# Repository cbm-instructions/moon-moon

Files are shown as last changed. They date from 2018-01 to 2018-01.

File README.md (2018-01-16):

# How to make Halexa

<p align="center">

</p>

## Einleitung
Halexa hilft dem Nutzer dabei einen gesünderen Schlafrythmus zu bekommen, indem sie den Nutzer motiviert abends das Handy rechtzeitig wegzulegen.
Zusätzlich wird die Stimmung des Nutzers nach dem Schlaf abgefragt, um zusammen mit den gesammelten Schlafdaten, einen Rückschluss auf das Schlafverhalten des Nutzers zu schließen.
Das Ergebnis ist eine Statistik, die Laune, Schlafdauer und rechtzeitiges Schlafen in Relation setzt, um dem Nutzer zu zeigen, dass seine Tageslaune von der Schlafqualität abhängt.

## Challenge

> In einer Gesellschaft mit steigender Lebenserwartung, mangelnder Bewegung, sowie
steigendem Übergewicht sind Lösungen gefragt die langfristig helfen die
Gesundheitskosten zu reduzieren, indem sie Menschen zu einem gesünderen Leben
anhalten. Auch Technologie kann hier einen wertvollen Beitrag leisten, indem sie
Menschen dabei unterstützt sich mehr zu bewegen, mehr mit anderen Menschen
gemeinsam zu unternehmen, gesünder zu essen, ein anderes Schlafverhalten zu
entwickeln etc.
Inspiriert von dieser Entwicklung ist es das Ziel Ihrer Challenge, Ideen für „Health and
Well-being“ zu entwickelten und zu lauffähigen Demonstratoren umzusetzen. Diese
sollen zu einer Verbesserung von Wohlbefinden und Gesundheit beitragen. Es ist
dabei Ihre Aufgabe, „smarte“ Objekte zu erschaffen die das Wohlbefinden ihrer
Nutzer nachhaltig verbessern. Diese könne für Kinder, Berufstätige, Studierende,
Senioren oder andere Nutzergruppen sein. Zu diesen Objekten zählen
Außenanlagen, Möbel, Gebäude, Deko-Objekte, usw. Jedes dieser Objekte kann
durch Technologie erweitert werden und so Information sammeln, verbreiten oder
anzeigen. Dabei dürfen die Objekte auch spielerische Elemente besitzen. Eine
Anbindung dieser Objekte an Apps oder Fitnesstracker ist denkbar, steht aber nicht
im Mittelpunkt. Der Fokus Ihres Beitrags soll auf den „smarten Objekten“ liegen.

Daraus ergibt sich folgende Challenge:

> Wie könnten Menschen durch die Interaktion mit intelligenten
> Objekten mehr Wohlbefinden und/oder Gesundheit erlangen?

Zu dieser Challenge haben wir mehrere Interviews geführt, aus denen hervorging, dass viele Studenten zu wenig Schlafen. Einer der Gründe hierfür war, dass die Studenten viel Zeit an Smartphones vor dem Einschlafen verbringen. Das Gerät hält den Studenten durch Licht und Inhalt vom Schlafen ab. Das führt zu einem ungesunden Schlafrythmus und zur Müdigkeit am nächsten Tag. Diese kann zu weiteren Effekten führen, wie z.b. Motivationslosigkeit und einem späteren Einschlafen.

Aufgrund dieser Erkentnisse haben wir den folgenden POV formuliert.

### POV

  > Wie können wir verhindern, dass Studenten vor dem Einschlafen zu lange ihre Zeit,
  in der sie schlafen könnten, mit elektronischen Geräten verschwenden umso ihren
  Schlafrhythmus zu verbessern.

## Bauanleitung

Die Anleitung so wie liste aller benötigten Materialien befindet sich [hier](INSTRUCTIONS.md).

## Code

Der Code für das Projekt wurde in C++ geschrieben und befindet sich [hier](code/).

### Zustandsautomat und die Bedienung

<p align="center">

</p>

Halexa benutzt einen Zustandsautomaten als Basis. Jeder Zustand hat eine eigene Anzeige und mögliche Aktionen.
Halexa beginnt im Standby-Zustand. Dieser Zustand zeigt lediglich die Bereitschaft von Halexa.

Ein tippen auf die Fläche führt zum History-Zustand. Er zeigt den Verlauf der vergangenen Tage an. Ein blauer Punkt zeigt den aktuellen, unbewerteten Tag. Im Uhrzeigersinn vom blauen Punkt aus findet man die vergangenen Tage. Dabei ist der Punkt direkt neben dem blauen Punkt der gestrige Schlaf, der nächste der vorgestrige usw. Nach einer gewissen Zeit schaltet Halexa wieder in den Standby-Zustand.

Sobald die Schlafenszeit erreicht ist (aktuell im Quellcode festgelegt auf 10 Sekunden nach jeder vollen Minute), wechselt Halexa aus dem Standby- und History-Zustand in den SleepingTime-Zustand. Dieser macht den Nutzer darauf aufmerksam, dass er sein Handy weglegen sollte und schlafen gehen sollte. Legt der Nutzer sein Handy ab, wird über den TimeIn-Zustand, ein reiner Animations- und Verzögerungszustand, in den Sleep-State gewechselt.
Verpasst der Nutzer die Schlafenszeit, geht das Gerät in den Standby und wiederholt den Alarm nach einiger Zeit. Es ist zu beachten, dass Halexa das Verpassen speichert. Dieses fließt in die Bewertung als "zu spät schlafen gegangen" ein.

Wird nach dem Schlaf das Handy wieder hochgenommen, erkennt Halexa nach einer kurzen, abbrechbaren, TimeOut-Periode, das Ende des Schlafs und geht in den Bewertungs-Zustand.

Im Bewertungszustand, der ebenfalls einen Standby erlaubt, Hat der Nutzer die Möglichkeit durch Antippen des aufleuchtenden Sektors, seine Stimmung nach dem Schlaf zu bewerten. Fühlt er sich gut und ausgeschlafen, wählt er grün. Falls er müde und schlecht gelaunt ist, wählt er rot. Die Bewertung ist bis zum nächsten Schlafenszeitpunkt möglich. Wird dieser erreicht, geht Halexa wieder in den SleepingTime-Zustand und bewertet den Schlaf negativ. Das soll den Nutzer motivieren rechtzeitig, aber zu einem flexiblen Zeitpunkt, zu bewerten.

## Bewertung des Schlafs

Der Schlaf wird anhand folgender drei Kriterien bewertet:

* rechtzeitiges Schlafen gehen
* ausreichende Schlaflänge
* Laune nach dem Schlaf

Jedes der Kriterien kann der Schlafbewertung einen oder keinen Punkt hinzufügen. Somit sind die Punktzahlen null bis drei möglich.

Ein Schlaf mit drei Punkten wird als sehr positiv bewertet und erhält eine deutlich grüne Farbe in der Statistik.
Ein Schlaf mit weniger als drei Punkten wird als eher negativ betrachtet und resultiert in den rot wirkenden Farben: hellorange (zwei Punkte), dunkelorange (ein Punkt), rot (null Punkte).

Es entsteht also eine Darstellung, die tendenziell die zwei Gruppen "positiv" und "negativ" darstellt,aber in den Punktebereichen null bis zwei trotzdem eine Differenzierung erlaubt.

Ziel der halexa ist es dem Nutzer zu zeigen, dass das Einhalten der drei Schlafkriterien, zu einer besseren Stimmung führen kann. Im idealen Fall zeigt die Statistik eine allmählich grüner werdende Historie.

## Ideen zur Weiterentwicklung

1. Einsätzen eines Vibrationsmotors unter der obersten Platte für Vibrationsfeedback bei der Benutzung der Platte als Eingabegerät.

2. Erweiterung um Einstellungsmenü um Schlafenszeit, Weckzeit und länge des Schlafes einzustellen.

3. Hinzufügen von Kapazitiven Buttons um die oben erwähnten Einstellungen vorzunehmen (Drucksensoren zu ungenau).

4. Erweiterung der Nutzergruppe. Es können beispielsweise andere Ablenkungen, wie Zeitschriften und Bücher, weggelegt werden.

5. Technische Anbindung an Home-Automation z.B. IFTTT oder NFC-Trigger

6. Erweiterung um einen echten persistenten Speicher. Aktuell ist die Statistik nur vorhanden, wenn das Gerät an ist. Sie liegt im flüchtigen Speicher.

7. Erweiterung um ein präzises Zeitmodul.

#### Optische Verbesserungen

1. Absenken der obersten Platte, damit sie mit dem LED-Ring auf einer Höhe ist.

2. Die allgemeine Größe verringern.

3. Höherwertiges Material.

## Das Team

Adrian Endrich und Christopher Hansen

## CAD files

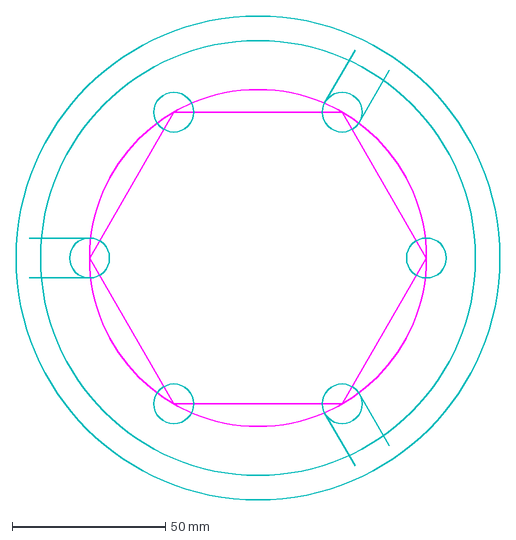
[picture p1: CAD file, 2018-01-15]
lasercutter/komplett.dxf
158.0 x 158.0 mm

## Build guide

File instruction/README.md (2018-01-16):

# Bauanleitung

In diesem Abschnitt befindet sich die komplette Anleitung zum Bau von Halexa. Der Code für den Arduino befindet sich [hier](https://github.com/cbm-instructions/moon-moon/tree/master/code/).

## Materialien und Werkzeuge

### Materialien
* Arduino Uno
* 3x Force Resistance Sensor
* 1 Neopixel LED Ring (4/4)
* Sperrholzplatte 4x460x61 mm
* Kabel
* 1 x Streifenrasterplatine
* 5 Pin Stiftleiste
* 3x 6 Pin Stiftleiste
* 2x 8 Pin Stiftleiste
* 5 x 10 kΩ Widerstände
* Holzleim
* Klebeband
* Rundstab 12 x 12 mm 0,5m (Buche)
* Schmirgelpapier
* Doppelseitiges Klebeband
* Plexiglassscheibe 170x170 mm
* Lötzinn
* Gummiband oder Schnur

### Werkzeuge
* Laser Cutter
* Dremel
* Lötkolben
* Zange
* Heißklebepistole
* Teppichmesser

## Vorbereitung

### Benötigte Vorkenntnisse

* Grundlegende handwerkliche Kentnisse
* Arduino Kentnisse
* Löten
* C++ (alles)

### Zusammenlöten des LED-Rings

### Drucken der Platten

Als erstes werden die SVG-Dateien für den Laser Cutter benötigt. Diese können [hier](https://github.com/cbm-instructions/moon-moon/tree/master/lasercutter/) heruntergeladen werden.

Es müssen folgende SVG-Dateien geschnitten werden hierzu wird die Sperrholzplatte (4x460x61 mm) benutzt:

* Grundplatte.svg
* Stelzenhalter.svg
* LedRingHalterung.svg
* Kabelplatte.svg
* DruckplatteUnten.svg
* DruckplatteOben.svg

* Den größeren der beiden Mäntel in Matel.svg

**Tipp:** Beim schneiden des Mantels ist es wichtig die Stärke des Lasers zu erhöhen, da dieser sonst nicht komplett durchschneidet und der Mantel sonst leicht bricht.

Die geschnittenen Platten sollten ungefähr so aussehen:

<p align="center">
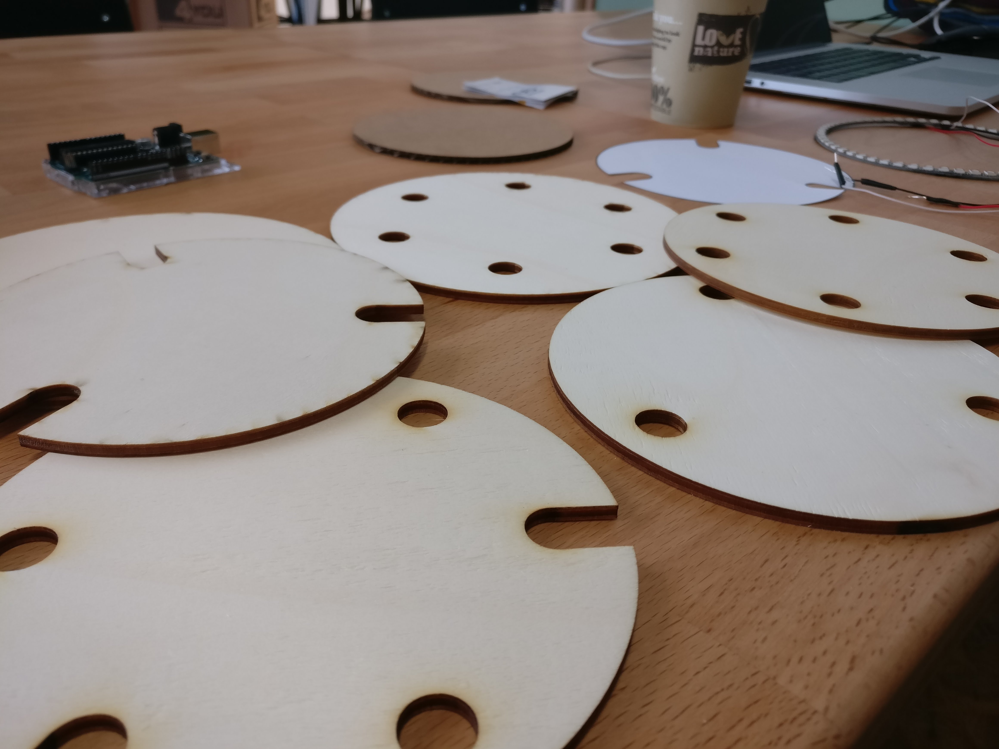
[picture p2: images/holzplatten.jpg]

</p>

Als letztes wird noch einmal die LedRingHalterung benötigt aber diesmal mit der Plexiglassscheibe (170x170 mm). Diese liegt später auf dem LED-Ring.

<p align="center">
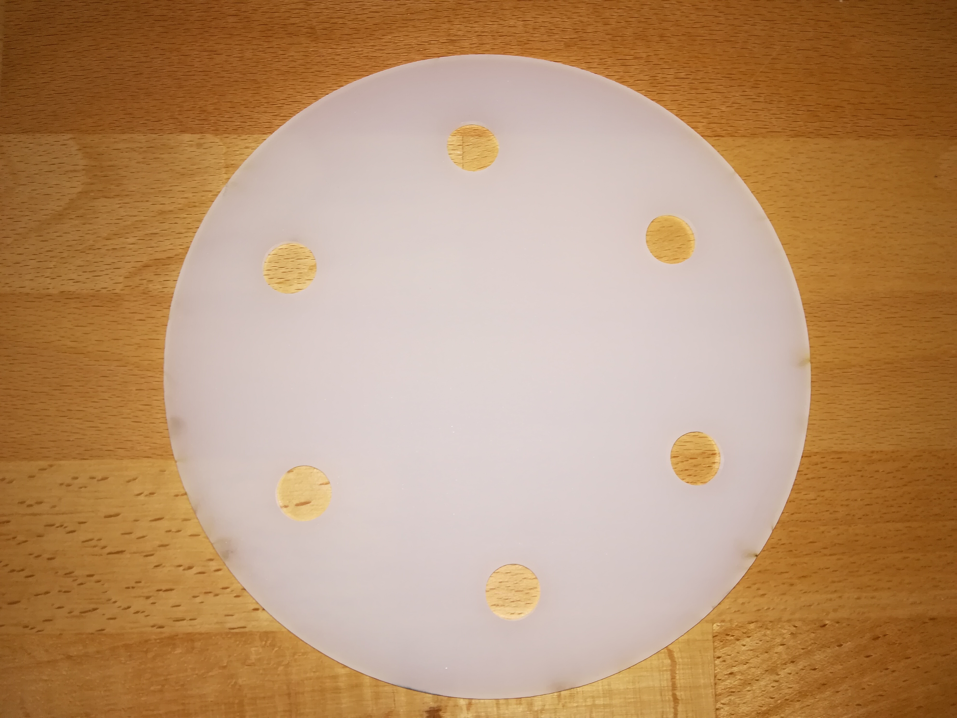
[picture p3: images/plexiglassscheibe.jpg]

</p>

## Schritt für Schritt Anleitung

#### 1. Verkablen der drei Drucksensoren
In diesem Schritt werden die Drucksensoren verkabelt und über eine Platine verbunden, so dass sie später einfacher mit dem Arduino verbunden werden können.

**Benötigte Materialien für diesen Schritt:**
  * Kabel
  * Die drei Drucksensoren
  * Streifenrasterplatine
  * 5 Pin Stiftleiste
  * 2x 6 Pin Stiftleiste
  * 5 x 10 kΩ Widerstände
  * Lötkolben

Als erstes sollten Sie die drei Drucksensoren mit Kabeln verlöten.

<p align="center">
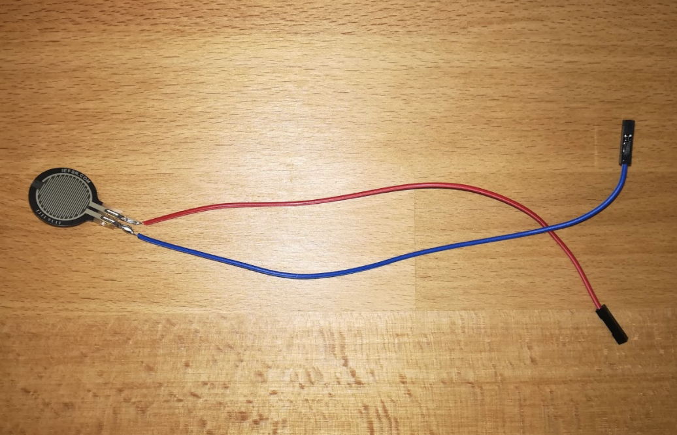
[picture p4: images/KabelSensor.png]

</p>

Danach bauen Sie eine Steckplatine um alle drei Drucksensoren später mit dem Arduino zu verbinden. Die obere waagerechte Steckleiste ist für die Grounds. An den linkesten Stecker dieser Steckleiste wird der Ground des Arduinos befestigt.
An alle anderen Pins werden die Grounds von den drei Drucksensoren befestigt (die zwei zusätzlichen Stecker dienen nur als Ersatz). Der Ground ist mit jeweils einem Widerstand mit jeder der anderen Grounds verbunden. Die Input Pins des Arduinos werden mit den Pins auf der exakt gegenüberliegenden Seite der Grounds verbunden. Die linke horizontale Steckerleiste wird benutzt um alle Sensoren mit dem 5V Eingang des Arduinos zu verbinden.

<p align="center">
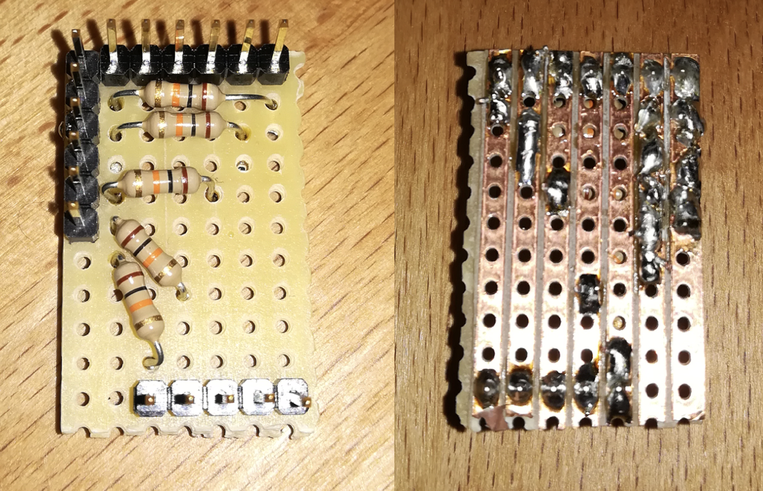
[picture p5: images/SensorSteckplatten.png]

</p>

#### 2. Fertigung der Bodenplatte mit Sensoren

In diesem Schritt werden die Sensoren an die Bodenplatte geklebt und die Stelzenhalterplatte befestigt.

**Benötigte Materialien für diesen Schritt:**
  * Stelzenhalterplatte
  * Bodenplatte
  * Die drei Drucksensoren
  * Holzleim
  * Rundstab 12 x 12 mm 0,5m (Buche)
  * Klebeband
  * Heißklebepistole

Schnittreste vom Laser Cutter:
<p align="center">
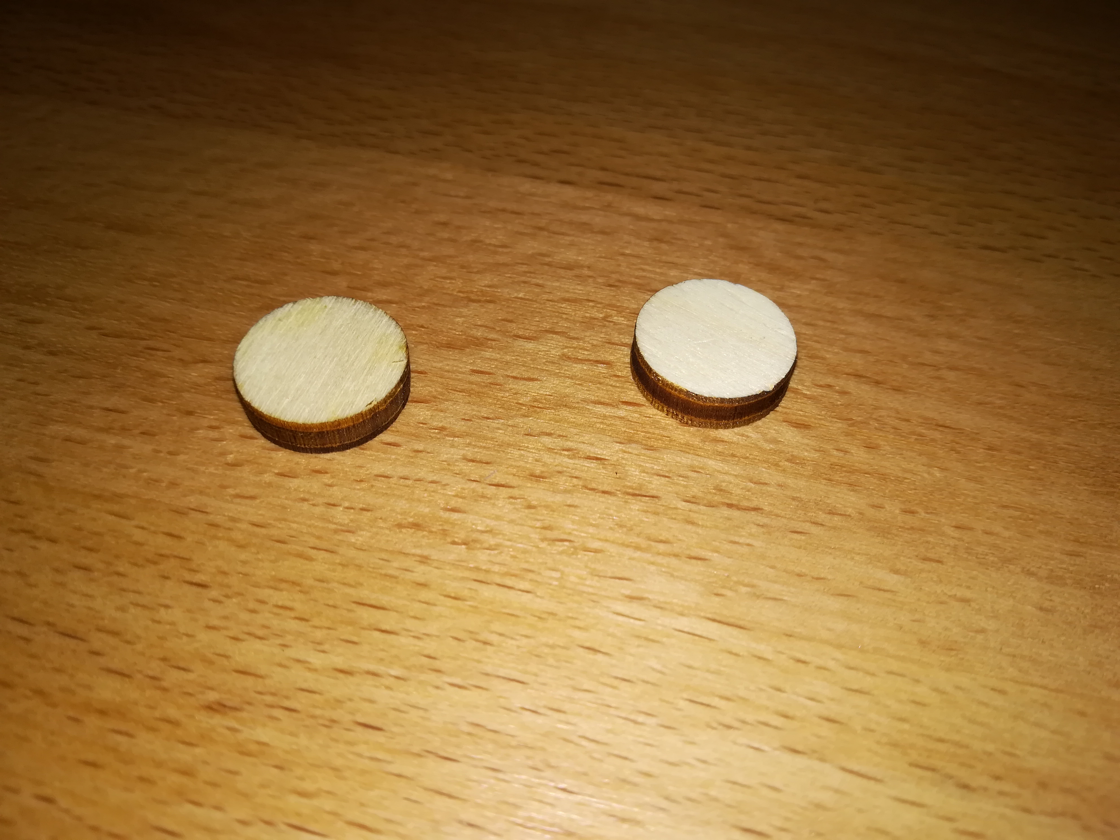
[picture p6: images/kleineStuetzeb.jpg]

</p>

Als erstes sollten Sie die Stelzenhalterplatte mittig auf die Bodenplatte legen und die Stellen markieren an denen die Löcher sind. Auf diese Stellen werden nun die Drucksensoren geklebt (diese haben bereits eine Klebefläche). Danach kann die Stelzenhalterplatte wie vorher auf die Bodenplatte gelegt werden. Wir haben die runden Schnittreste des Laser Cutters als Zwischenstücke benutzt um die Bodenplatte mit der Stelzenhalterplatte zu befästigen, so dass diese nicht die Sensoren berührt. Schneiden Sie drei gleichlange Stücke vom Rundstab (je 70 mm) ab . Kleben Sie diese wie auf dem unteren Bild leicht versetzt zu den Drucksensoren auf die Stelzenhalterplatte (Mit Holzleim oder Heißklebepistole).
Am Schluss können Sie noch die Kabel mit Klebeband fixieren und die Kabel mit der bereits erstellten Steckplatine verbinden.

<p align="center">
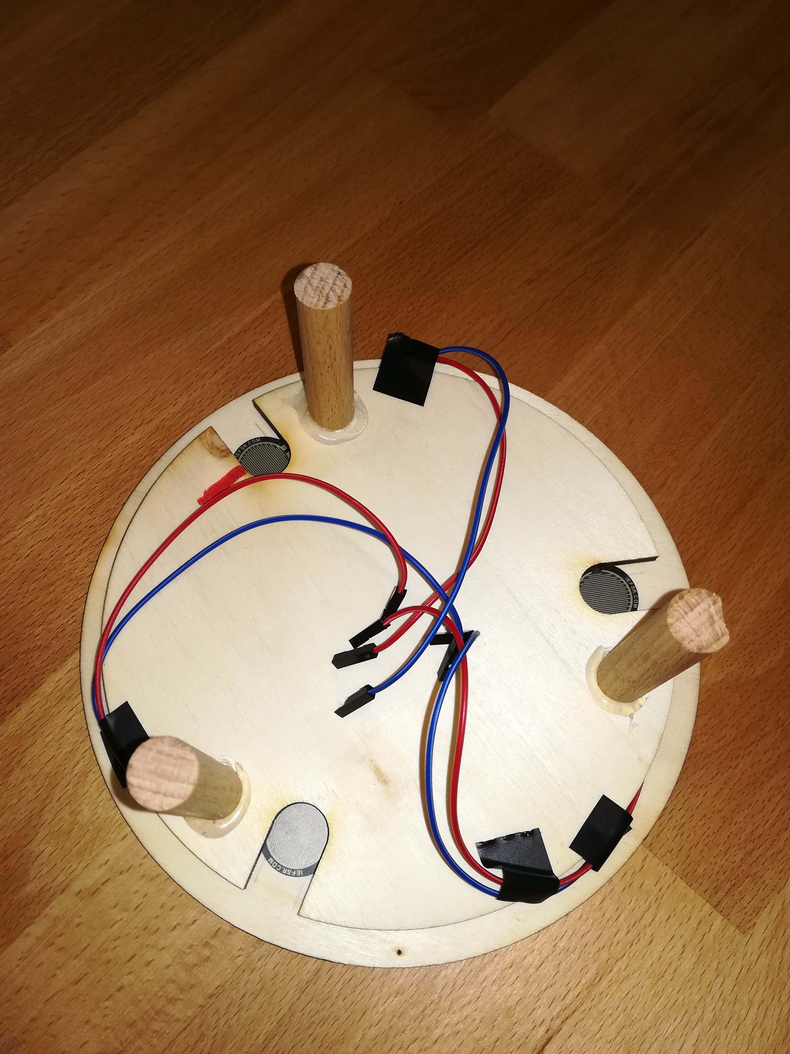
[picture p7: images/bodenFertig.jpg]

</p>

#### 3. Fertigung der LED-Ring Platte

In diesem Schritt wird die Platte die den LED-Ring hält erstellt, welche dann an der zuvor erstellten Bodenplatte befestigt wird.

**Benötigte Materialien für diesen Schritt:**
  * LedRingHalterung
  * Kabelplatte
  * Holzleim
  * Neopixel LED Ring
  * Doppelseitiges Klebeband
  * Die zuvor erstelle Bodenplatte
  * Holzstab

Kleben Sie die Kabelplatte mit Holzleim auf die LedRingHalterung, so dass sich alle sechs Löcher exakt überlappen. Nachdem der Leim getrocknet ist können Sie den LED-Ring wie im Bild, mit dem doppelseitigen Klebeband, auf den übergeblieben Rand kleben. Achten Sie darauf, dass die Kabel des LED-Rings durch eine der drei hierfür vorgesehenen Kabellöcher laufen. Als letztes kleben Sie, mit Holzleim, die erstellte LED-Ring Platte auf die zuvor erstellte Bodenplatte wie im Bild unten zu sehen ist.

**ACHTUNG:** Achten Sie darauf das die Löcher durch die später die Stelzen der Druckplatte laufen (nicht die Kabellöcher) exakt über den Drucksensoren liegen. **Tipp:** Benutzen Sie den Rundstab als fixierung.

<p align="center">
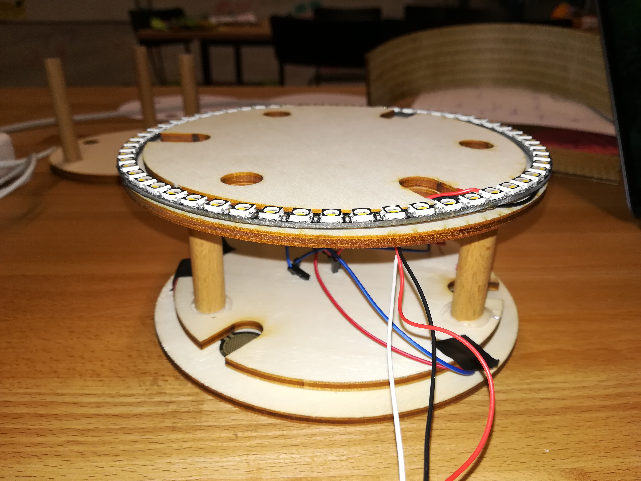
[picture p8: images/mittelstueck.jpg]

</p>

#### 4. Fertigung der Druckplatte

In diesem Schritt wird die Druckplatte erstellt auf die später das Handy gelegt werden soll.

**Benötigte Materialien für diesen Schritt:**
  * DruckplatteOben
  * DruckplatteUnten
  * Rundstab 12 x 12 mm 0,5m (Buche)
  * Heißklebepistole
  * Holzleim
  * Dremel oder Schmirgelpapier

Als erstes kleben Sie die DruckplatteOben und die DruckplatteUnten mit Holzleim so zusammen das drei der Löcher exakt übereinande liegen. In die drei von der oberen Platte verschlossen Löcher werden nun drei gleich große Holzstäbe (78 mm) festgeklebt (Holzleim oder Heißklebepistole). Die unteren Enden der Holzstäbe können mit Schmirgelpapier oder einem Dremel an den Seiten verkleinert werden so das diese die Drucksensoren besser treffen.

<p align="center">
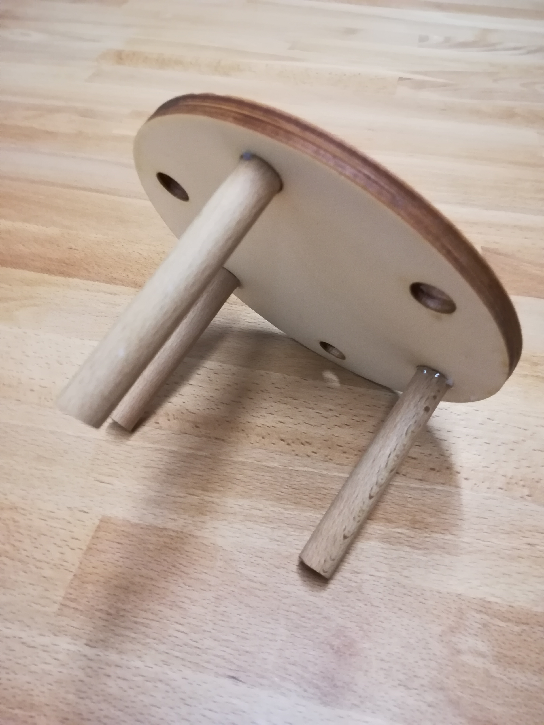
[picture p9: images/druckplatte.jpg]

</p>

#### 5. Arduino Steckplatte

In diesem Schritt wird eine Steckplatte erstellt die mit den Drucksensoren und dem Led-Ring verbunden ist. Diese Steckplatte kann dann später einfach auf den Arduino gesteckt werden und vereinfacht die Verkabelung.

**Benötigte Materialien für diesen Schritt:**
  * Streifenrasterplatine
  * Kabel
  * 1x 6 Pin Stiftleiste
  * 2x 8 Pin Stiftleiste
  * Arduino
  * Teppichmesser

Als erstes schneiden Sie eine Stück aus der Streifenrasterplatine aus welches der größe des Arduinos entspricht. Nehmen Sie den Arduino und Stecken Sie die 8 Pin Stiftleiste in Power die 6 Pin Stiftleiste in den Analog In und die letzte 8 Pin Stiftleiste in die Digital Eingänge 0-7. Nun können sie einfach die Streifenrasterplatine auf die Stifleisten legen und diese festlöten. Achten Sie darauf das die Streifen von der einen Seite zu anderen des Arduinos verlaufen. Nachdem die Stiftleisten an der Streifenrasterplatine festgelötet sind können sie die Platine abnehmen. Mit einem Teppichmesser können Sie nun wie im Bild in der mitte der Platine das Kupfer abkratzen.

<p align="center">
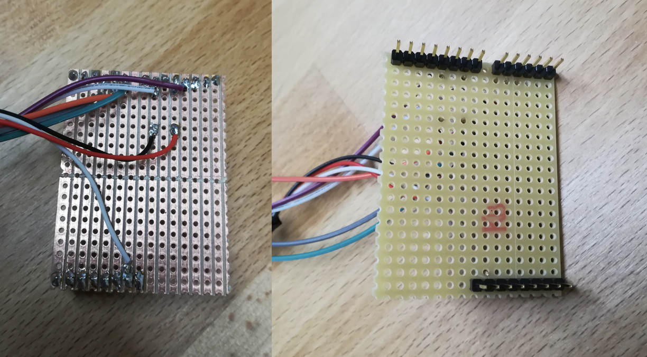
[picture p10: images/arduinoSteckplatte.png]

</p>

Nun zur verkabelung. Löten Sie jeweils das Power Kabel des LED-Rings und der Sensorstckplatte an den 5 V Streifen der Steckplatte. Genauso werden jeweils der Ground des LED-Rings und der Sensorsteckplatte an den Ground Streife der Steckplatte gelötet.
Zuletzt Löten sie die drei Inputkabel der Sensoren an die Analog Eingänge A0 - A2

#### 6. Zusammensetzen

In diesem Schritt werden alle vorher erstellen Komponenten zusammengesetzt.

**Benötigte Materialien für diesen Schritt:**
  * Erstellte Bodenplatte
  * Erstellte Druckplatte
  * LED-Ring Platte
  * Holzmantel
  * Arduino und Steckplatte
  * Plexiglassscheibe
  * Doppelseitiges Klebeband
  * Dremel
  * Gummiband oder Schnur

Als erstes verkabeln Sie den LED-Ring und die Drucksensoren mit dem Arduino und befestigen diesen mit doppelseitigen Klebeband an der Bodenplatte.

<p align="center">
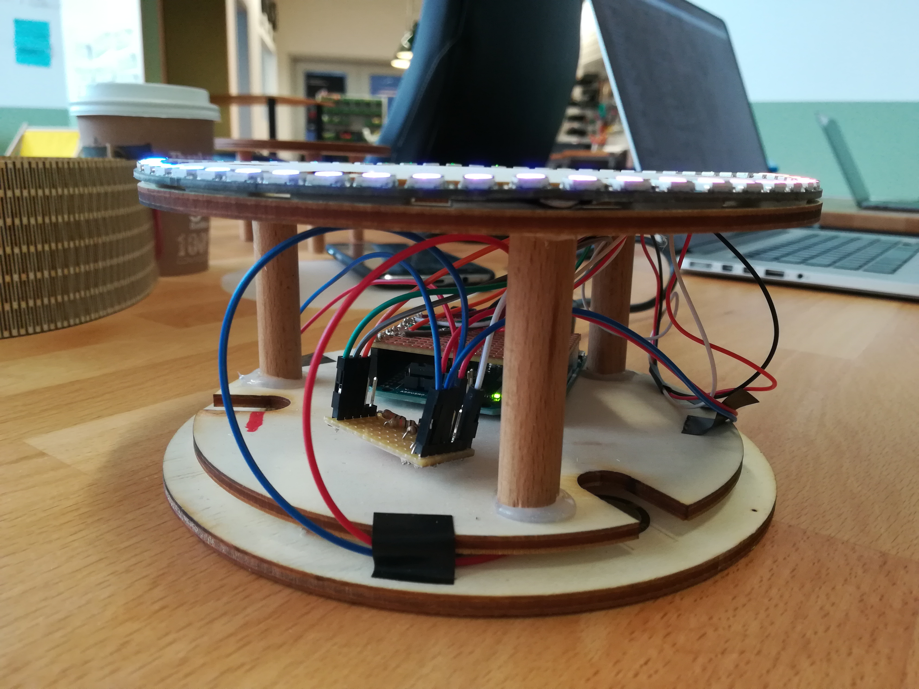
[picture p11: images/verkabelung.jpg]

</p>

Dann können Sie die Druckplatte in die dafür vorgesehenen Löcher stecken. Zwischen die Druckplatte und die LED-Ring Platte kommt die Plexiglassscheibe.

<p align="center">
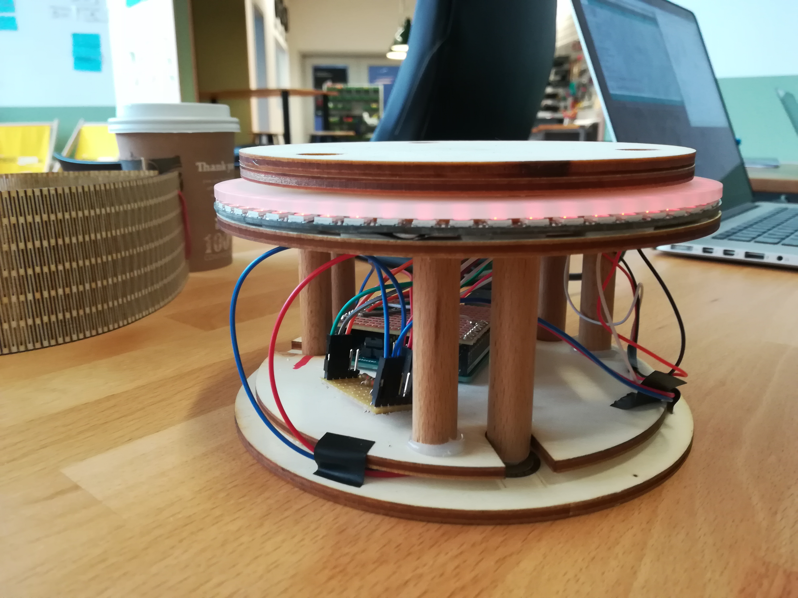
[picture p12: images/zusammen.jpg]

</p>

Als letztes wird der Holzmantel um die Konstruktion gelegt. Aus Wartungszwecken haben wir den Mantel nur mit einem Gummiband befestigt. Hierzu können Sie mit einem Dremel vier Löcher in den Mantel machen und dann mit einer Schnur oder einem Gummiband diesen befestigen. Die bleibende Öffnung ist für das Stromkabel des Arduinos. 

<p align="center">
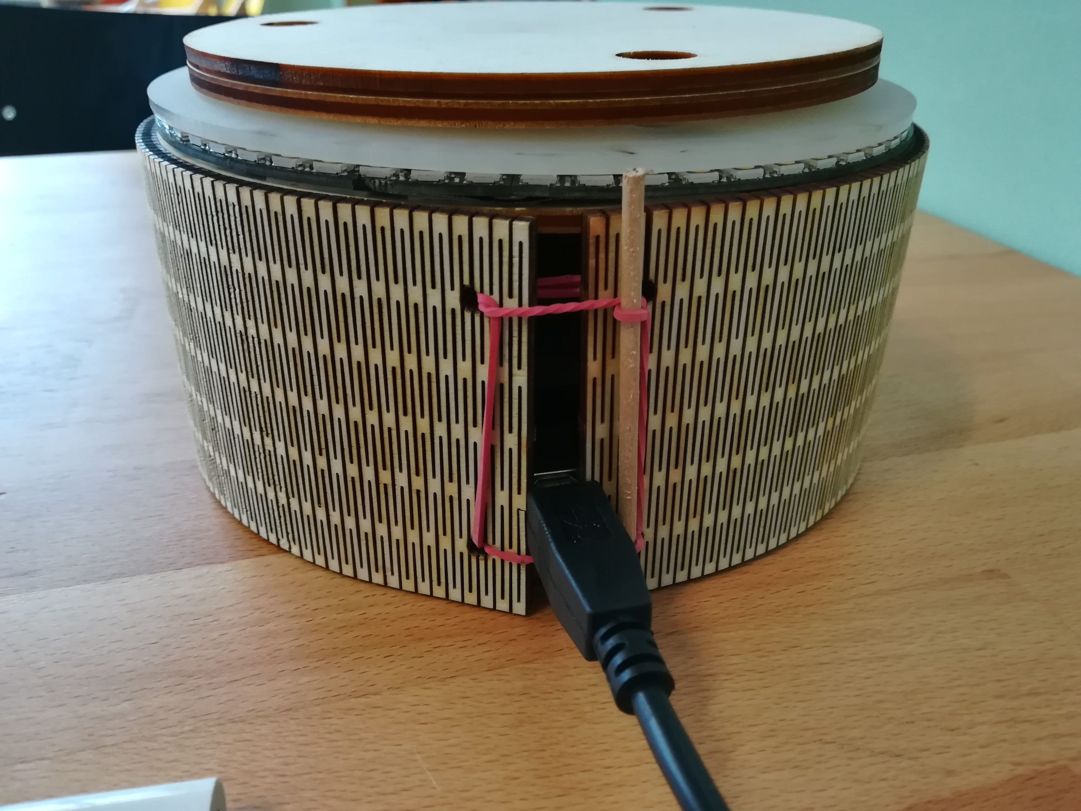
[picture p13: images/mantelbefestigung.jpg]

</p>

#### Allgemeine Tipps

* Die Druckplatte kann optional auf der Rückseite mit Gewichten versehen um so ein erhöhtes Grundgewicht zu erhalten. Dadurch arbeiten die Sensoren wesentlich besser da sie vor allem bei wenig Druck dazu neigen ungenau zu sein. (Schwellwert im Programm muss dazu angepasst werden)

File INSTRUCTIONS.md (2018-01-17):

# Bauanleitung

In diesem Abschnitt befindet sich die komplette Anleitung zum Bau von Halexa. Der Code für den Arduino befindet sich [hier](code/arduino/).

## Materialien und Werkzeuge

### Materialien
* Arduino Uno
* 3x Force Resistance Sensor
* 4 Neopixel LED 1/4 Ringe mit jeweils 15 Pixeln, insgesamt also 60 Pixel
* Sperrholzplatte 4x460x61 mm
* Kabel
* 1 x Streifenrasterplatine
* 5 Pin Stiftleiste
* 3x 6 Pin Stiftleiste
* 2x 8 Pin Stiftleiste
* 5 x 10 kΩ Widerstände
* Holzleim
* Klebeband
* Rundstab 12 x 12 mm 0,5m (Buche)
* Schmirgelpapier
* Doppelseitiges Klebeband
* milchige Plexiglassscheibe 170x170 mm
* Lötzinn
* Gummiband oder Schnur

### Werkzeuge
* Laser Cutter
* Dremel
* Lötkolben
* Zange
* Heißklebepistole
* Teppichmesser

## Vorbereitung

### Benötigte Vorkenntnisse

* Grundlegende handwerkliche Kenntnisse
* Arduino Kenntnisse
* Löten
* C++: Pointer, Klassen, Speicheralloziierung und Grundlagen sollten bekannt sein
* Das Konzept eines Zustandsautomaten sollte bekannt sein

### Zusammenlöten des LED-Rings

Die 4 Viertelringe müssen zu einem Ring zusammengelötet werden und es müssen die drei notwendigen Leitungen als Litzen herausgelegt werden.
Das folgende Bild zeigt einen zusammengelöteten Ring ohne Litzen.

<p align="center">
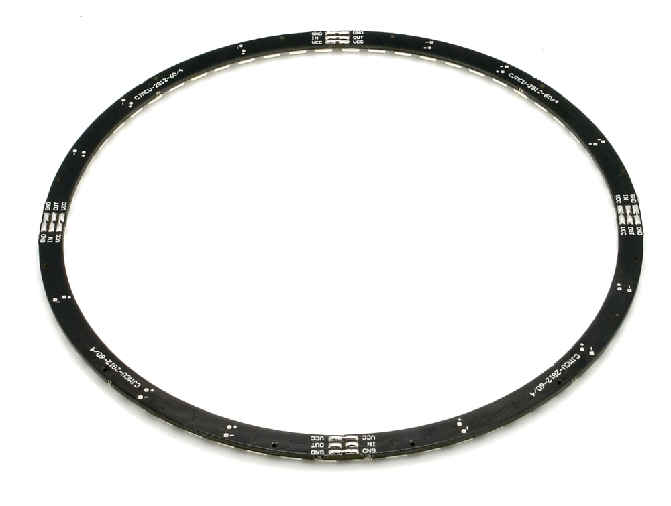
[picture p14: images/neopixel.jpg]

</p>

An einen der vier GND, IN und VCC Kontakte müssen jetzt noch Litzen mit einer Länge von circa 10cm angelötet werden.

### Schneiden der Platten

Als erstes werden die SVG-Dateien für den Laser Cutter benötigt. Diese können [hier](lasercutter/) heruntergeladen werden. Wichtig dabei, ist die Schnittreste des Cutters nicht wegzuwerfen. Sie werden später benötigt.

Es müssen folgende SVG-Dateien geschnitten werden hierzu wird die Sperrholzplatte (4x460x61 mm) benutzt:

* Grundplatte.svg
* Stelzenhalter.svg
* LedRingHalterung.svg
* Kabelplatte.svg
* DruckplatteUnten.svg
* DruckplatteOben.svg
* Den größeren der beiden Mäntel in Mantel.svg

**Tipp:** Beim Schneiden des Mantels ist es wichtig die Stärke des Lasers zu erhöhen, da dieser sonst nicht komplett durchschneidet und der Mantel leicht bricht.

**Tipp:** Die .dxf Datei erlaubt es die technische Zeichnung im Rohformat zu öffnen. Hierzu kann z.B. LibreCad verwendet werden.

Die geschnittenen Platten sollten ungefähr so aussehen:

<p align="center">

</p>

Als letztes wird noch einmal die LedRingHalterung benötigt aber diesmal mit der Plexiglassscheibe (170x170 mm). Diese liegt später auf dem LED-Ring.

<p align="center">

</p>

## Schritt für Schritt Anleitung

#### 1. Verkablen der drei Drucksensoren
In diesem Schritt werden die Drucksensoren verkabelt und über eine Platine verbunden, so dass sie später einfacher mit dem Arduino verbunden werden können.

**Benötigte Materialien für diesen Schritt:**
  * Kabel
  * Die drei Drucksensoren
  * Streifenrasterplatine
  * 5 Pin Stiftleiste
  * 2x 6 Pin Stiftleiste
  * 5 x 10 kΩ Widerstände
  * Lötkolben

Als erstes sollten Sie die drei Drucksensoren mit Kabeln verlöten.

<p align="center">

</p>

Danach bauen Sie eine Steckplatine um alle drei Drucksensoren später mit dem Arduino zu verbinden. Die obere waagerechte Steckleiste ist für die Grounds. An den vertikalen Stecker dieser Steckleiste wird der Ground des Arduinos befestigt.
An alle anderen Pins werden die Grounds von den drei Drucksensoren befestigt (die zwei zusätzlichen Stecker dienen nur als Ersatz). Der Ground ist über jeweils einen Widerstand mit jedem der anderen Grounds verbunden. Die Input Pins des Arduinos werden mit den Pins auf der exakt gegenüberliegenden Seite der Grounds verbunden. Die linke horizontale Steckerleiste wird benutzt um alle Sensoren mit dem 5V Eingang des Arduinos zu verbinden.

Ein logischer Schaltplan und Aufbau befindet sich [hier](#logischer-schaltplan-und-aufbau).

<p align="center">

</p>

#### 2. Fertigung der Bodenplatte mit Sensoren

In diesem Schritt werden die Sensoren an die Bodenplatte geklebt und die Stelzenhalterplatte befestigt.

**Benötigte Materialien für diesen Schritt:**
  * Stelzenhalterplatte
  * Bodenplatte
  * Die drei Drucksensoren
  * Holzleim
  * Rundstab 12 x 12 mm 0,5m (Buche)
  * Klebeband
  * Heißklebepistole

Zusätzlich muss man die Schnittreste des Laser Cutters benutzen:
<p align="center">

</p>

Als erstes sollten Sie die Stelzenhalterplatte mittig auf die Bodenplatte legen und die Stellen markieren an denen die Löcher sind. Auf diese Stellen werden nun die Drucksensoren geklebt (diese haben bereits eine Klebefläche). Danach kann die Stelzenhalterplatte wie vorher auf die Bodenplatte gelegt werden. Wir haben die runden Schnittreste des Laser Cutters als Zwischenstücke benutzt um die Bodenplatte mit der Stelzenhalterplatte zu befästigen, so dass diese nicht die Sensoren berührt. Schneiden Sie drei gleichlange Stücke vom Rundstab (je 70 mm) ab . Kleben Sie diese wie auf dem unteren Bild leicht versetzt zu den Drucksensoren auf die Stelzenhalterplatte (Mit Holzleim oder Heißklebepistole).
Am Schluss können Sie noch die Kabel mit Klebeband fixieren und die Kabel mit der bereits erstellten Steckplatine verbinden.

<p align="center">

</p>

#### 3. Fertigung der LED-Ring Platte

In diesem Schritt wird die Platte die den LED-Ring hält erstellt, welche dann an der zuvor erstellten Bodenplatte befestigt wird.

**Benötigte Materialien für diesen Schritt:**
  * LedRingHalterung
  * Kabelplatte
  * Holzleim
  * Neopixel LED Ring
  * Doppelseitiges Klebeband
  * Die zuvor erstelle Bodenplatte
  * Holzstab

Kleben Sie die Kabelplatte mit Holzleim auf die LedRingHalterung, so dass sich alle sechs Löcher exakt überlappen. Nachdem der Leim getrocknet ist können Sie den LED-Ring wie im Bild, mit dem doppelseitigen Klebeband, auf den übergeblieben Rand kleben. Achten Sie darauf, dass die Kabel des LED-Rings durch eine der drei hierfür vorgesehenen Kabellöcher laufen.

Zusätzlich muss der Übergang vom 1. zum 60. Pixel exakt wie auf dem folgenden Bild ausgerichtet werden.

<p align="center">
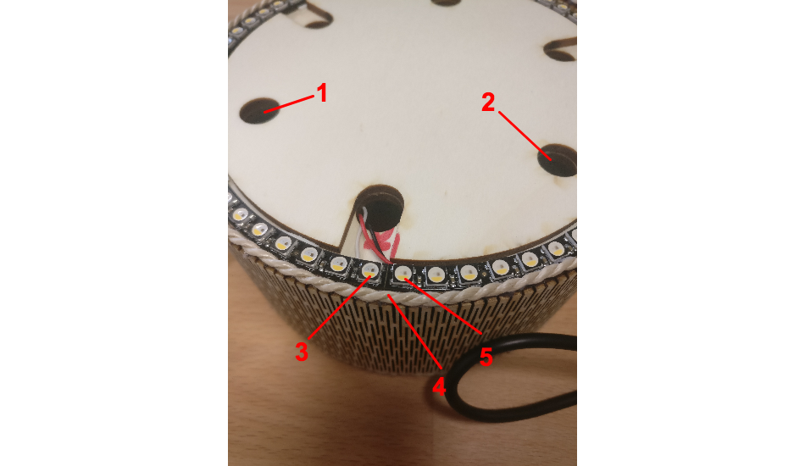
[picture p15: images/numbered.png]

</p>

* (3) 0. Pixel des Rings (Der erste Pixel nach dem Anlötpunkt der IN-Leitung)
* (4) Lötstelle zwischen zwei Viertelringen muss eine exakte Verlängerung der Kabelführungskante (rot) sein
* (5) 59. Pixel des Rings

Sind (3) bis (5) korrekt ausgerichtet, dann gilt für (1) und (2)

* (1) Diese Stelze + Sensor ist für die Bewertungslogik ein "positiver" Sektor und der Sensor wird an A1 angeschlossen
* (2) Diese Stelze + Sensor ist für die Bewertungslogik ein "negativer" Sektor und der Sensor wird an A2 angeschlossen

Als letztes kleben Sie, mit Holzleim, die erstellte LED-Ring Platte auf die zuvor erstellte Bodenplatte wie im Bild unten zu sehen ist.

**ACHTUNG:** Achten Sie darauf, dass die Löcher, durch die später die Stelzen der Druckplatte laufen (nicht die Kabellöcher) exakt über den Drucksensoren liegen.

**Tipp:** Benutzen Sie den Rundstab als Fixierung.

<p align="center">

</p>

#### 4. Fertigung der Druckplatte

In diesem Schritt wird die Druckplatte erstellt auf die später das Handy gelegt werden soll.

**Benötigte Materialien für diesen Schritt:**
  * DruckplatteOben
  * DruckplatteUnten
  * Rundstab 12 x 12 mm 0,5m (Buche)
  * Heißklebepistole
  * Holzleim
  * Dremel oder Schmirgelpapier

Als erstes kleben Sie die DruckplatteOben und die DruckplatteUnten mit Holzleim so zusammen das drei der Löcher exakt übereinande liegen. In die drei von der oberen Platte verschlossen Löcher werden nun drei gleich große Holzstäbe (78 mm) festgeklebt (Holzleim oder Heißklebepistole). Die unteren Enden der Holzstäbe können mit Schmirgelpapier oder einem Dremel an den Seiten verkleinert werden, so dass diese die Drucksensoren besser treffen.

<p align="center">

</p>

**Tipp:** Die Druckplatte kann optional auf der Rückseite mit Gewichten versehen um so ein erhöhtes Grundgewicht zu erhalten. Dadurch arbeiten die Sensoren wesentlich besser da sie vor allem bei wenig Druck dazu neigen ungenau zu sein. Der Sensor kommt so in seinen optimalen Arbeitsbereich. Der Schwellwert im Programm muss dazu angepasst werden [phoneIsThereThreshold in ForceSensors.cpp](code/arduino/ForceSensors.cpp).

#### 5. Arduino Steckplatte

In diesem Schritt wird eine Steckplatte erstellt die mit den Drucksensoren und dem Led-Ring verbunden ist. Diese Steckplatte kann dann, wie ein Arduino Shield, später einfach auf den Arduino gesteckt werden und vereinfacht die Verkabelung.

**Benötigte Materialien für diesen Schritt:**
  * Streifenrasterplatine
  * Kabel
  * 1x 6 Pin Stiftleiste
  * 2x 8 Pin Stiftleiste
  * Arduino
  * Teppichmesser

Als erstes schneiden Sie eine Stück aus der Streifenrasterplatine aus, welches der Größe des Arduinos entspricht. Nehmen Sie den Arduino und Stecken Sie die 8 Pin Stiftleiste in Power die 6 Pin Stiftleiste in die Analogeingänge und die letzte 8 Pin Stiftleiste in die Digitaleingänge 0-7. Nun können Sie einfach die Streifenrasterplatine auf die Stiftleisten legen und diese festlöten. Achten Sie darauf, dass die Streifen von der einen Pinseite zu der anderen Pinseite des Arduinos verlaufen. Nachdem die Stiftleisten an der Streifenrasterplatine festgelötet sind, können sie die Platine abnehmen. Mit einem Teppichmesser können Sie nun wie im Bild in der mitte der Platine das Kupfer abkratzen um den Kontakt zu unterbrechen.

<p align="center">

</p>

Löten Sie jeweils das Power-Kabel des LED-Rings und der Sensorsteckplatte an den 5V Streifen der Steckplatte. Genauso werden jeweils der Ground des LED-Rings und der Sensorsteckplatte an den Ground-Streifen der Steckplatte gelötet.
Zuletzt löten Sie die drei Inputkabel der Sensoren an die Analog Eingänge A0 - A2.
Bedenken Sie dabei die Ausrichtung aus Kapitel [Fertigung der LED-Ring Platte](#3-fertigung-der-led-ring-platte).
An A1 wird der Sensor angeschlossen, der im Uhrzeigersinn von LED 0 liegt. An A2 wird der Sensor angeschlossen, der gegen den Uhrzeigersinn von LED 0 liegt.

Ein logischer Schaltplan und Aufbau befindet sich [hier](#logischer-schaltplan-und-aufbau).

#### 6. Zusammensetzen

In diesem Schritt werden alle vorher erstellen Komponenten zusammengesetzt.

**Benötigte Materialien für diesen Schritt:**
  * Erstellte Bodenplatte
  * Erstellte Druckplatte
  * LED-Ring Platte
  * Holzmantel
  * Arduino und Steckplatte
  * Plexiglassscheibe
  * Doppelseitiges Klebeband
  * Dremel
  * Gummiband oder Schnur

Als erstes verkabeln Sie den LED-Ring und die Drucksensoren mit dem Arduino und befestigen diesen mit doppelseitigen Klebeband an der Bodenplatte.

<p align="center">

</p>

Dann können Sie die Druckplatte in die dafür vorgesehenen Löcher stecken. Zwischen die Druckplatte und die LED-Ring Platte kommt die Plexiglassscheibe.

**Tipp:** Durch Klebeungenauigkeiten kann es sein, dass die Stelzen an einer der Führungsöffnungen reiben, oder die Stelzen nicht exakt die Sensoren berühren. In diesem Fall eignet es sich die Stelzen an den kritischen Stellen leicht mit dem Dremel anzupassen. So wird der reibungslose Ablauf ermöglicht.

<p align="center">

</p>

Als letztes wird der Holzmantel um die Konstruktion gelegt. Aus Wartungszwecken haben wir den Mantel nur mit einem Gummiband befestigt. Hierzu können Sie mit einem Dremel vier Löcher in den Mantel bohren und dann mit einer Schnur oder einem Gummiband befestigen. Die bleibende Öffnung ist für das Stromkabel des Arduinos.

<p align="center">

</p>

**Tipp:** Für eine saubere und permanente Ummantelung muss der Mantel ca 1cm länger gedruckt werden. Zusätzlich müssen Kabelöffnungen gebohrt werden und ein permanenter Befestigungsmechanismus gefunden werden.

Halexa kann nun in Betrieb genommen werden.

## Anpassung der Software und Entfernen der Demo-Daten

Aktuell gibt es noch keine Einstellungsmöglichkeiten. Die Software muss direkt bearbeitet werden und auf den Arduino gespielt werden.

Die [arduino.ino](code/arduino/arduino.ino) erlaubt das Bestimmen des Startzustands und der PIN Nummern.
in der setup Methode gibt es eine Reihe von handgeschriebenen Demo Daten, die entfernt werden sollten.

Parameter zur Druckplatte befinden sich in der [ForceSensors.cpp](code/arduino/ForceSensors.cpp). Hier können Schwellwerte für Handys und Berührungen gesetzt werden. Auch können die Sensoren gewichtet werden, damit sie gleichstarke Werte liefern.

Parameter zur Zeit befinden sich in der [Clock.cpp](code/arduino/Clock.cpp). Hier kann die Schlafenszeit definiert werden. Durch Anpassen der Logik in isSleepTime() kann (nach der Anbindung einer besseren Uhr) eine korrekte Schlafenszeit nach Stunde (hoursOfDay) und Minuten (minutesOfHour) erkannt werden.
Es kann auch eine optimale Schlafdauer festgelegt werden.

Die [NeoPatterns.cpp](code/arduino/NeoPatterns.cpp) erlaubt zusammen mit allen State-Klassen die Anpassung der Animationen und Farben.

Die [Memory.cpp](code/arduino/Memory.cpp) kann genutzt werden um einen echten persistenten Speicher anzubinden.

## Logischer Schaltplan und Aufbau

Zur Darstellung wurde ein LED Stripe genommen. Dieser hat die gleichen Anschlüsse wie der zu verwendende Ring

<p align="center">
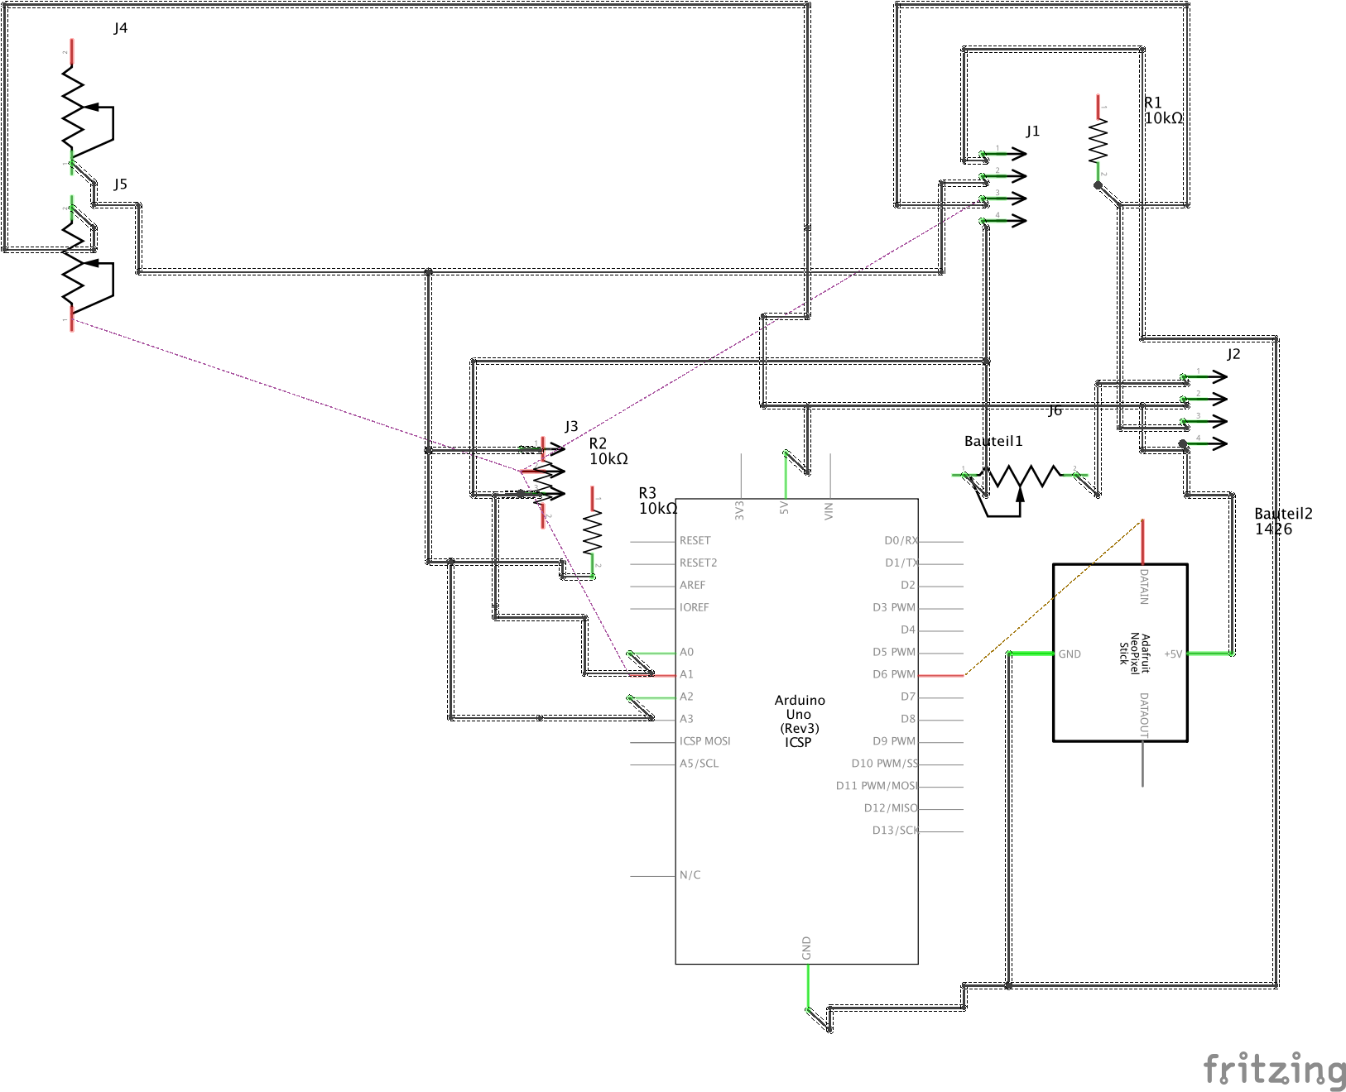
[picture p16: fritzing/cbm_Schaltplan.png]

</p>

<p align="center">
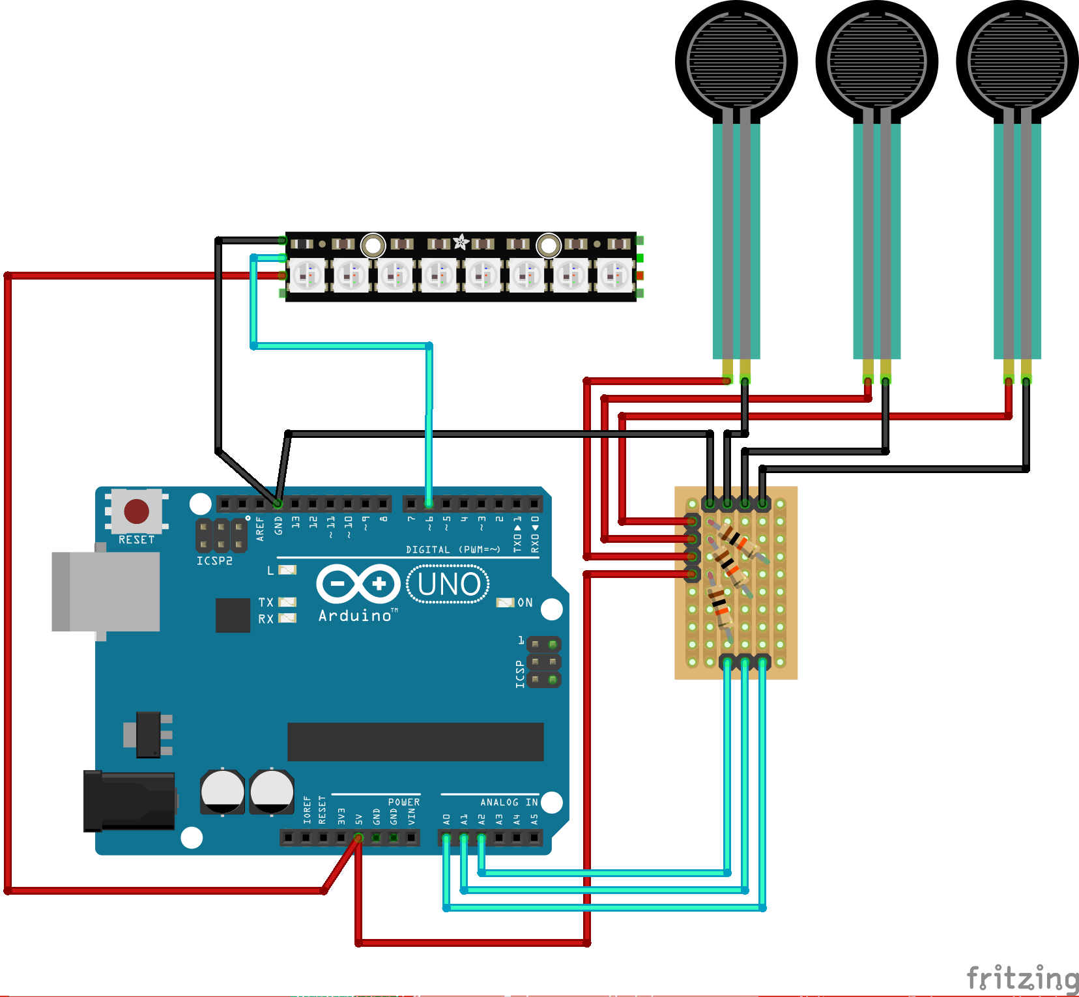
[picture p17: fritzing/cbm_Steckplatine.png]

</p>

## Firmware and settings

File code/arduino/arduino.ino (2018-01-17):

#define NEOPIXEL_PIN 6
#define FS_A_PIN A0
#define FS_B_PIN A1
#define FS_C_PIN A2

#include "FiniteStateMachine.h"
#include "StandbyState.h"
#include "HistoryState.h"
#include "RateState.h"
#include "NeoPatterns.h"
#include "ForceSensors.h"
#include "Memory.h"

FiniteStateMachine* fsm;
NeoPatterns* ring;
ForceSensors* forceSensors;
Clock* clock;
Memory* memory;

void setup() {
  Serial.begin(9600);

  forceSensors = new ForceSensors(FS_A_PIN, FS_B_PIN, FS_C_PIN);
  forceSensors->setup();

  ring = new NeoPatterns(60, NEOPIXEL_PIN, NEO_RGBW + NEO_KHZ800);
  ring->begin();
  ring->RainbowCycle(3, FORWARD);
  ring->Update();

  clock = new Clock();
  memory = new Memory();

  fsm = new FiniteStateMachine(new StandbyState(), ring, forceSensors, clock, memory);
  fsm->setup();

    //DEMO DATA
  saveDay(0);
  saveDay(0);
  saveDay(0);
  saveDay(0);
  saveDay(1);
  saveDay(0);
  saveDay(3);
  saveDay(0);
  saveDay(0);
    saveDay(0);
    saveDay(0);
    saveDay(0);
    saveDay(0);
    saveDay(1);
    saveDay(0);
    saveDay(0);
    saveDay(3);
    saveDay(0);
    saveDay(1);
    saveDay(0);
    saveDay(0);
    saveDay(1);
    saveDay(0);
    saveDay(1);
    saveDay(0);
    saveDay(1);
    saveDay(1);
    saveDay(3);
    saveDay(1);
    saveDay(1);
    saveDay(1);
    saveDay(0);
    saveDay(1);
    saveDay(2);
    saveDay(1);
    saveDay(1);
    saveDay(2);
    saveDay(2);
    saveDay(2);
    saveDay(0);
    saveDay(3);
    saveDay(2);
    saveDay(2);
    saveDay(2);
    saveDay(3);
    saveDay(3);
    saveDay(3);
    saveDay(2);
    saveDay(3);
    saveDay(3);
    saveDay(3);
  saveDay(3);
  saveDay(2);
  saveDay(3);
  saveDay(3);
  saveDay(3);
  saveDay(3);
  saveDay(3);
  saveDay(3);
  saveDay(2);

}

void saveDay(int level) {
    memory->setSleptEnough(true);
    memory->setCurrentOnTime(true);
    memory->setCurrentMood(true);

    if(level == 0) {
        memory->setSleptEnough(false);
        memory->setCurrentOnTime(false);
        memory->setCurrentMood(false);
    } else if(level == 1){
        memory->setSleptEnough(false);
        memory->setCurrentOnTime(false);
    } else if (level == 2){
        memory->setSleptEnough(false);
    }

    memory->persistCurrentDayInfo();

}

void loop() {
  forceSensors->loop();
  ring->Update();
  fsm->loop();
  //Serial.println(freeRam());
}

int freeRam ()
{
  extern int __heap_start, *__brkval;
  int v;
  return (int) &v - (__brkval == 0 ? (int) &__heap_start : (int) __brkval);
}

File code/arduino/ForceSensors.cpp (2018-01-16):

#include "ForceSensors.h"

const int phoneIsThereThreshold = 200; //minimal force needed to recognize phone
const int phoneIsThereTimeThreshold = 3000; //minimal time a phone needs to be on the pressure sensor to recognize it as there or gone
const float weightA = 1;
const float weightB = 1;
const float weightC = 1;
const int numReadings = 10;
const int delayTime = 10;

boolean phoneIsThere = false;
float readings[numReadings];      // the readings from the analog input
int readIndex = 0;              // the index of the current reading
float total = 0;                  // the running total
float average = 0;                // the average
int phoneIsThereTime = 0;

ForceSensors::ForceSensors(int sensorPinA, int sensorPinB, int sensorPinC) {
    this->sensorPinA = sensorPinA;
    this->sensorPinB = sensorPinB;
    this->sensorPinC = sensorPinC;
}

void ForceSensors::setup() {
    for (int thisReading = 0; thisReading < numReadings; thisReading++) {
        readings[thisReading] = 0;
    }
}

boolean ForceSensors::wasTouched() {
    return average > phoneIsThereThreshold;
}

int ForceSensors::getDominantSensor() {

    float minDiff = 100.0;
    float a = weightA * analogRead(this->sensorPinA);
    float b = weightB * analogRead(this->sensorPinB);
    float c = weightC * analogRead(this->sensorPinC);

    if ((a - b) > minDiff && (a - c) > minDiff) {
        return 0;
    } else if ((b - a) > minDiff && (b - c) > minDiff) {
        return 1;
    } else if ((c - b) > minDiff && (c - a) > minDiff) {
        return 2;
    } else return 3;

}

void ForceSensors::loop() {

    // subtract the last reading:
    total = total - readings[readIndex];
    // read from the sensor:
    readings[readIndex] = (weightA * analogRead(this->sensorPinA) + weightB * analogRead(this->sensorPinB) +
                           weightC * analogRead(this->sensorPinC)) / 3;
    // add the reading to the total:
    total = total + readings[readIndex];
    // advance to the next position in the array:
    readIndex = readIndex + 1;

    // if we're at the end of the array...
    if (readIndex >= numReadings) {
        // ...wrap around to the beginning:
        readIndex = 0;
    }

    // calculate the average:
    average = total / numReadings;

    Serial.println(average);

    if (average > phoneIsThereThreshold) {
        phoneIsThereTime += delayTime;
        if (phoneIsThereTime >= phoneIsThereTimeThreshold) {
            phoneIsThereTime = phoneIsThereTimeThreshold;
            phoneIsThere = true;
        }
    } else {
        phoneIsThereTime -= delayTime;
        if (phoneIsThereTime <= 0) {
            phoneIsThereTime = 0;
            phoneIsThere = false;
        }
    }

}

boolean ForceSensors::isPhoneThere() {
    return phoneIsThere;
}

long ForceSensors::getPhoneIsThereTime() {
    return phoneIsThereTime;
}

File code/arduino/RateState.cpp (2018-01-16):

//
// Created by Adrian Endrich on 15.01.18.
//

#include "RateState.h"
#include <Arduino.h>
#include "Memory.h"
#include "NeoPatterns.h"
#include "ForceSensors.h"
#include "StandbyState.h"
#include "SleepState.h"
#include "HistoryState.h"
#include "RateStandbyState.h"
#include "SleepingTimeState.h"

void RateState::setup() {
    this->ring->Rate();
    long x = millis();
    this->memory->setSleptEnough((millis() - this->memory->sleepStartedAt) > this->clock->getOptimalSleepLength());
    Serial.print("Set SleptEnaugh: ");
    Serial.println((x - this->memory->sleepStartedAt) > this->clock->getOptimalSleepLength());
};

void RateState::loop() {
    //do not check for touches directly

    if (this->getRunningTime() > 500 && this->forceSensors->wasTouched()) {
        // write rating to history

        switch (this->forceSensors->getDominantSensor()) {
            case 2:
                this->memory->setCurrentMood(false);
                Serial.print("Set CurrentMood: ");
                Serial.println(false);
                this->memory->persistCurrentDayInfo();
                this->changeState(new HistoryState());
                break;
            case 1:
                this->memory->setCurrentMood(true);
                Serial.print("Set CurrentMood: ");
                Serial.println(true);
                this->memory->persistCurrentDayInfo();
                this->changeState(new HistoryState());
                break;
        }

    }

    if (this->clock->isSleepTime()) {
        this->memory->setCurrentMood(false);
        Serial.print("Set CurrentMood: ");
        Serial.println(false);
        this->memory->persistCurrentDayInfo();
        this->changeState(new SleepingTimeState());
    }

    if (this->getRunningTime() > 10000) {
        this->changeState(new RateStandbyState());
    }

};

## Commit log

2018-01-15 added some Materials
2018-01-15 added svg files
    [CBM.dxf]
2018-01-15 renamed svgs and added image and instruction
    [komplett.dxf]
2018-01-16 changed to bolt
2018-01-16 updating code to current threshold
2018-01-17 2 minutes alarm and moving code/ to code/arduino/
2018-01-17 moving code/ to code/arduino/ in instructions
